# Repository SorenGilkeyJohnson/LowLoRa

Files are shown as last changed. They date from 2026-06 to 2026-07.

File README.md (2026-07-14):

# Low Power LoRa Weather Station

A solar powered, batteryless LoRa (expandable) sensor node powered from a supercapacitor charged by a small solar cell using an energy harvester. This was built around the Semtech SX1262 LoRa transceiver (US band; 915 MHz) and the low power MSPM0L110x MCU (TI; M0+), this board is a monitoring platform for anything you might want! The board is made around the solar cell and is roughly 23x24mm. 

<p align="center">
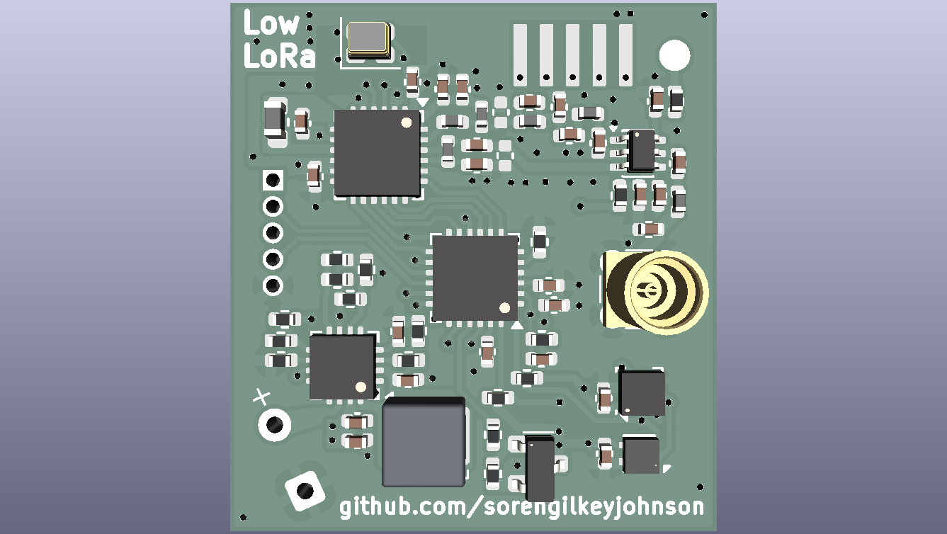
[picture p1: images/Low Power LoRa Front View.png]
Front View
  
</p>

## Overview

When researching this concept, I had found a few previous examples of this being done (e.g. [nootropicdesign](hackster.io/nootropicdesign/solar-powered-lora-weather-station-36b6ea)). I had not found an example, however, of a board that was fully self contained. When I was researching the component selection I really wanted it to be fully on board, which drove my decision to use a supercapacitor over a traditional Li-ION cell (almost none are SMD) and made me want to use a chip or PCB antenna. I found a supercapacitor that should work (this is my first time working with them), but I did not have enough room for an onboard antenna. Because of this I decided to add an external antenna through a connector. Another reason for this is the solar cell can block the RF waves from propagating properly. My project is still fairly unique from any existing solution, because I have found that it is rare to use a SMD solar cell. This is one of the biggest ones available on the market, as most are designed for handheld calculators. 
    Figuring out the power budget was very difficult for this project, and that was probably the thing I spent the most time on. Thankfully, the SX1262 datasheet had detailed power budget options, and I was able to base it off of that (almost all of my battery consumption should be from that). This project taught me a lot about the importance of component selection! (I probably spent 2 times longer on this than any other project I had done vs the routing). 
    When I get the board, I hope I can get it so that it is watertight. I have already done some research into gaskets for the humidity sensor (as this needs access to the outside world to get a good reading), but this seems pretty hard to do. There is a version of the sensor that has this built in, but it is far more expensive and is hard to get from most suppliers. I plan to use silicone around the PCB to protect the border of the solar cell from accidental damage, and put a piece of fiberglass over it. I made sure to keep all the parts that would petrude together, so I should have a slightly easier time designing the case. I hope I can get this board and test it out soon!

## Key Features

* **Ultra Low Power** This PCB should run at ultra low power, and may be able to run continuously in good sunlight (although it is designed for far less).
* **Small Board Size** The board for this is quite compact, and is mainly constrained by the size of the solar cell.
* **LoRa Transmit** This should be able to transfer over very long distances, and should be able to also extend range of other forming a "mesh"
* **Future expansion** Plentiful GPIO pins are broken out, so if one wanted to add more sensors, it would be as easy as soldering additional connectors to the PCB test pads.

## How It Works

1. The solar cell charges a supercapacitor through the BQ25504 energy harvesting IC, which is designed to extract power efficiently over a long period of time from very low amperage power sources. The datasheet mentioned being able to charge off of a piezoelectric element which would be way under the amount of current generated by a solar cell. Hopefully, this will overcome the natural discharge of the supercap.
2. A PMOS, switched by the MCU, gates power (VSYS) to the SX1262 and sensors, keeping the idle current as low as possible between transmissions because far less of the passive components are powered, and everything remains fully off.
3. The MSPM0L110x wakes periodically (very low sleep current ~<1uA; nothing compared to capacitor discharge), turns on the MOSFET to wake the sensors, reads the temperature/humidity and pressure sensors over I2C, and transmits the data over LoRa using the SX1262. Monitors the BAT_GOOD pin and turns everything off when it needs to!
4. The system was sized so that the supercapacitor can supply more than enough for the estimated ~15–30 mJ needed for a transmit burst. This part selection could be more conservative, but it was outside the range of ceramic capacitors, and there were not a lot of good low profile supercapacitor options.

## Hardware

| Main Components | Part | Notes |
| --- | --- | --- |
| LoRa Transceiver | SX1262 | Main IC, tuned for 915 MHz (US LoRa band) |
| Antenna | MMCX connector | External antenna due to PCB space constraints and having a metal backing (solar cell) |
| MCU | MSPM0L110x | I2C + SPI, wide voltage range, low cost, high availability from LCSC |
| Energy Harvester | BQ25504 | Manages charging from the solar cell and is very efficient. Gold standard for applications like this. |
| Solar Cell | KXOB121K04F-TR | very nice solar cell available on Digikey |
| Energy Storage | CXP-3R0335R-TW Supercapacitor | Low ESR; high capacitance; relatively space efficient |
| Load Switch | PMOS | Controlled by MCU to gate VSYS in order to save power for the rest of the system |
| Humidity/Temp Sensor | SHT4x | I2C |
| Pressure Sensor | LPS22HB | I2C |
| Antenna Switch | PE4259 | RF switch for the SX1262 (exact same component from reference design) |
| PCB Size | 23 mm x 25 mm | Large Solar Cell at a relatively high voltage compared to others on the market |

### 3D Renders

### PCB Layers
<p align="center">
  Front View
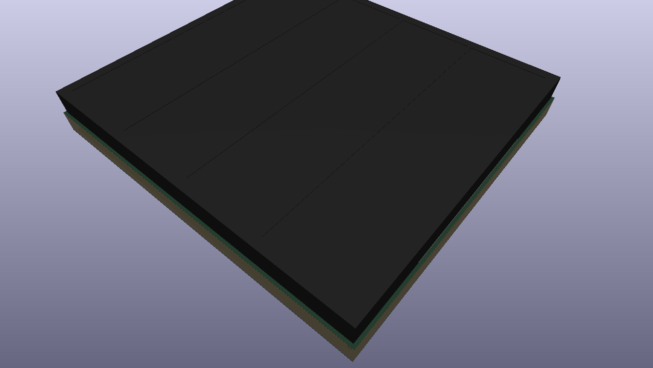
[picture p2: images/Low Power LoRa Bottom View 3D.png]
Bottom View
  
</p>

### PCB Layers

<p align="center">
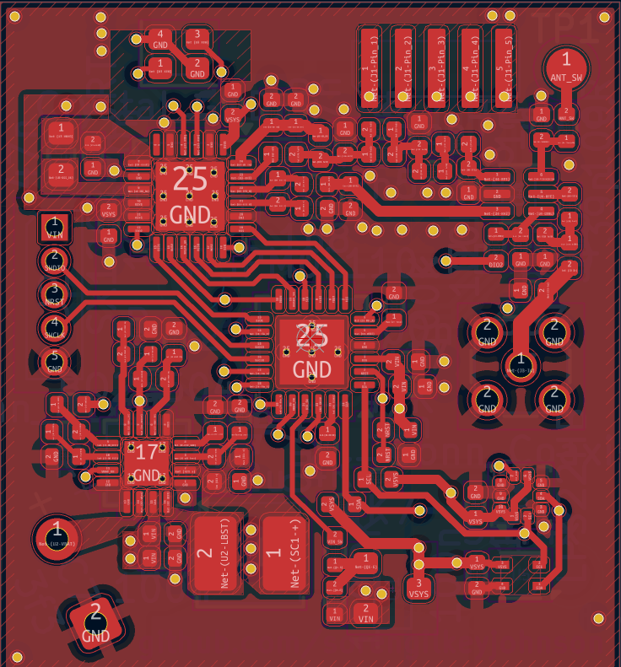
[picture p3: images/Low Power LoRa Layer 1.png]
Layer 1
  
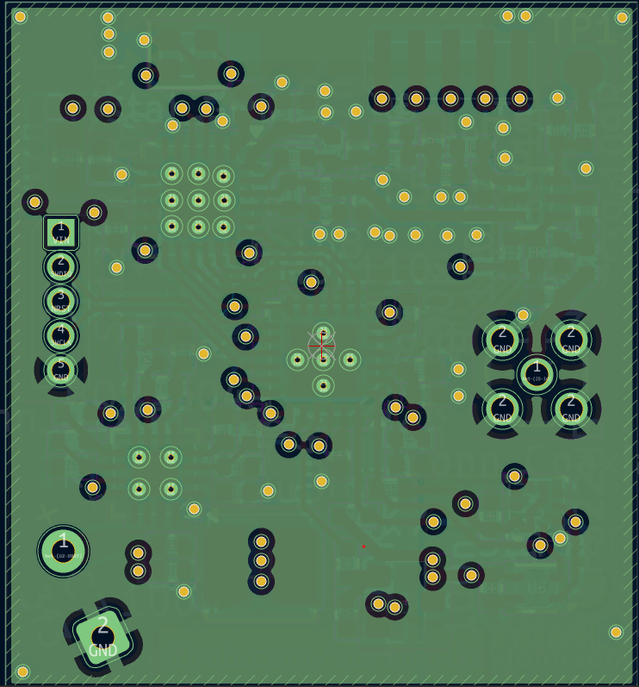
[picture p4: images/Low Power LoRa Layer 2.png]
Layer 2
  
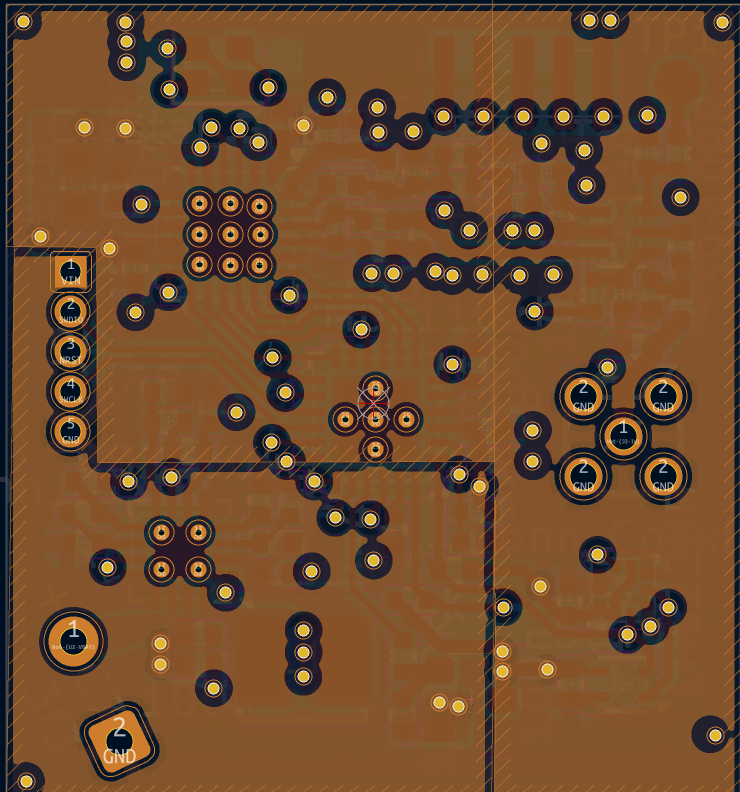
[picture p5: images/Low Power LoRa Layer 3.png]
Layer 3
  
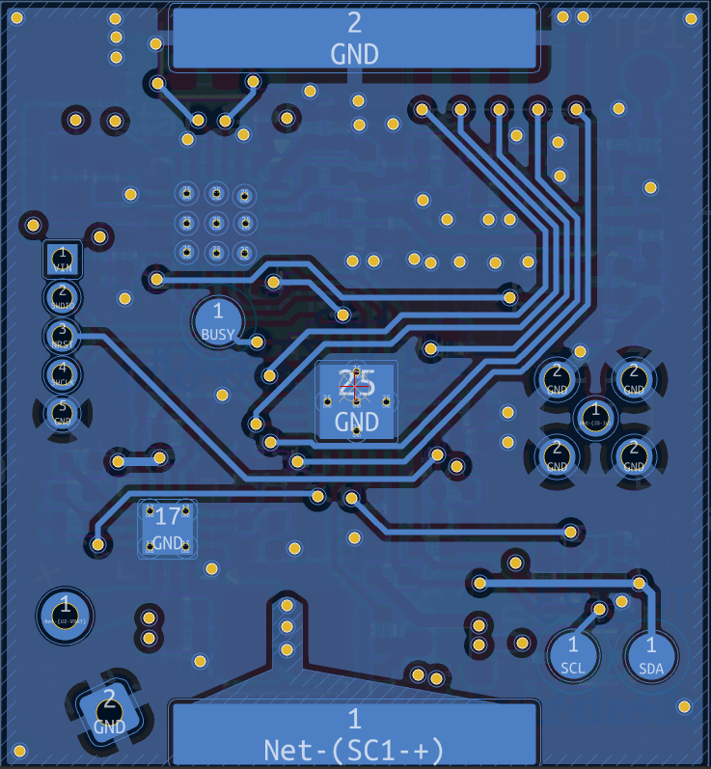
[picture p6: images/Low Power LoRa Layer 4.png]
Layer 4
  
</p>

Schematic: [`Low Power LoRa Schematic.pdf`](https://www.google.com/search?q=images/Low%2520Power%2520LoRa%2520Schematic.pdf)

## Repository Structure

```
.
├── KiCAD/
│  ├── Low Power LoRa.kicad_pcb     # PCB layout
│  ├── Low Power LoRa.kicad_prl     # Project local settings
│  ├── Low Power LoRa.kicad_pro     # Project file
│  └── Low Power LoRa.kicad_sch     # Schematic
├── fabrication/
│  ├── bom.csv                      # Bill of materials
│  ├── gerbers.zip                  # Gerber files for PCB fabrication
│  └── pick_and_place.csv           # Pick-and-place file for assembly
├── images/
│  ├── Low Power LoRa Bottom View 3D.png
│  ├── Low Power LoRa Front View.png
│  ├── Low Power LoRa Layer 1.png
│  ├── Low Power LoRa Layer 2.png
│  ├── Low Power LoRa Layer 3.png
│  ├── Low Power LoRa Layer 4.png
│  └── Low Power LoRa Schematic.pdf
├── LICENSE
└── README.md

```

## Ordering the Board

Fabrication files can be found here: [`fabrication/`](https://www.google.com/search?q=fabrication/) folder:
The BOM was generated using LCSC, so ignore the minimum part quantities (these get messed up due to MOQ). You should be able to use the KiCAD files to generate your own.

## Programming

The MSPM0L110x is programmed with the SWD header. I do not have the board yet, so I will update this section more later when I have more information about real-world testing.

## Acknowledgments

* SX1262 RF matching network and BQ25504 based on respective companies reference design
* Review from r/PrintedCircuitBoard! (Thank you!)

## License

See [`LICENSE`](https://www.google.com/search?q=LICENSE) for details.

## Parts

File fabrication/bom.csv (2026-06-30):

Reference | Qty | Value | DNP | Exclude from BOM | Exclude from Board | Footprint | Datasheet
C1,C5 | 2 | 10n |  |  |  | Capacitor_SMD:C_0402_1005Metric
C2,C6,C8 | 3 | 4u7 |  |  |  | Capacitor_SMD:C_0402_1005Metric
C3,C10,C11,C22,C29 | 5 | 100n |  |  |  | Capacitor_SMD:C_0402_1005Metric
C4 | 1 | 0u47 |  |  |  | Capacitor_SMD:C_0402_1005Metric
C7 | 1 | 3F3 |  |  |  | Capacitor_THT:CP_Radial_D8.0mm_P3.50mm
C9 | 1 | 1u |  |  |  | Capacitor_SMD:C_0402_1005Metric
C12 | 1 | 470n |  |  |  | Capacitor_SMD:C_0402_1005Metric
C13 | 1 | 47n |  |  |  | Capacitor_SMD:C_0402_1005Metric
C14,C23 | 2 | 1p8 |  |  |  | Capacitor_SMD:C_0402_1005Metric
C15 | 1 | 47p |  |  |  | Capacitor_SMD:C_0402_1005Metric
C16 | 1 | 2p4 |  |  |  | Capacitor_SMD:C_0402_1005Metric
C19 | 1 | 3p |  |  |  | Capacitor_SMD:C_0402_1005Metric
C20 | 1 | 5p6 |  |  |  | Capacitor_SMD:C_0402_1005Metric
C21,C26 | 2 | 39p |  |  |  | Capacitor_SMD:C_0402_1005Metric
C24,C25 | 2 | 1n |  |  |  | Capacitor_SMD:C_0402_1005Metric
C27,C28 | 2 | 3p3 |  |  |  | Capacitor_SMD:C_0402_1005Metric
J1 | 1 | Conn_01x05 |  |  |  | Connector_PinHeader_1.27mm:PinHeader_1x05_P1.27mm_Vertical_SMD_Pin1Left
J2 | 1 | Conn_01x05 |  |  |  | Connector_PinHeader_1.27mm:PinHeader_1x05_P1.27mm_Vertical
J3 | 1 | Conn_Coaxial |  |  |  | Connector_Coaxial:MMCX_Molex_73415-1471_Vertical
L1 | 1 | 22u |  |  |  | Inductor_SMD:L_Wuerth_LQFS-3818
L2 | 1 | 47n |  |  |  | Inductor_SMD:L_0603_1608Metric
L3 | 1 | 0R |  |  |  | Inductor_SMD:L_0402_1005Metric
L4 | 1 | 15n |  |  |  | Inductor_SMD:L_0402_1005Metric
L5 | 1 | 47n |  |  |  | Inductor_SMD:L_0402_1005Metric
L6 | 1 | 2n5 |  |  |  | Inductor_SMD:L_0402_1005Metric
L7 | 1 | 4n7 |  |  |  | Inductor_SMD:L_0402_1005Metric
L8 | 1 | 9n1 |  |  |  | Inductor_SMD:L_0402_1005Metric
Q1 | 1 | Si2301CDS |  |  |  | PCM_Package_TO_SOT_SMD_AKL:SOT-23 | https://www.tme.eu/Document/519498819e90b407235adccdceba4014/SI2301CDS-T1-GE3.pdf
R1 | 1 | 47K |  |  |  | Resistor_SMD:R_0402_1005Metric
R2,R3,R4,R5,R6,R7,R8,R9,R10 | 9 | R |  |  |  | Resistor_SMD:R_0402_1005Metric
R11,R12 | 2 | 100K |  |  |  | Resistor_SMD:R_0402_1005Metric
R13 | 1 | 10K |  |  |  | Resistor_SMD:R_0402_1005Metric
R14,R15 | 2 | 4K7 |  |  |  | Resistor_SMD:R_0402_1005Metric
R16,R17 | 2 | 100R |  |  |  | Resistor_SMD:R_0402_1005Metric
SC1 | 1 | KXOB121K04F-TR |  |  |  | Custom_Footprint_Purchase:KXOB121K04F-TR
TP1,TP2,TP3,TP4 | 4 | TestPoint |  |  |  | TestPoint:TestPoint_Pad_D1.5mm
U1 | 1 | MSPM0L110x |  |  |  | Package_DFN_QFN:VQFN-24-1EP_4x4mm_P0.5mm_EP2.45x2.45mm_ThermalVias | https://www.ti.com/lit/gpn/mspm0l1105
U2 | 1 | BQ25504 |  |  |  | Package_DFN_QFN:VQFN-16-1EP_3x3mm_P0.5mm_EP1.68x1.68mm_ThermalVias | http://www.ti.com/lit/ds/symlink/bq25504.pdf
U3 | 1 | SX1262IMLTRT |  |  |  | Package_DFN_QFN:QFN-24-1EP_4x4mm_P0.5mm_EP2.6x2.6mm | https://semtech.file.force.com/sfc/dist/version/download/?oid=00DE0000000JelG&ids=0682R00000IjPWSQA3
U4 | 1 | PE4259 |  |  |  | Package_TO_SOT_SMD:SOT-363_SC-70-6 | 4259-63
U5 | 1 | SHT4x |  |  |  | Sensor_Humidity:Sensirion_DFN-4_1.5x1.5mm_P0.8mm_SHT4x_NoCentralPad | https://sensirion.com/media/documents/33FD6951/624C4357/Datasheet_SHT4x.pdf
U7 | 1 | LPS22HH |  |  |  | Package_LGA:ST_HLGA-10_2x2mm_P0.5mm_LayoutBorder3x2y | https://www.st.com/resource/en/datasheet/lps22hh.pdf
Y1 | 1 | Crystal_GND24 |  |  |  | Crystal:Crystal_SMD_2520-4Pin_2.5x2.0mm

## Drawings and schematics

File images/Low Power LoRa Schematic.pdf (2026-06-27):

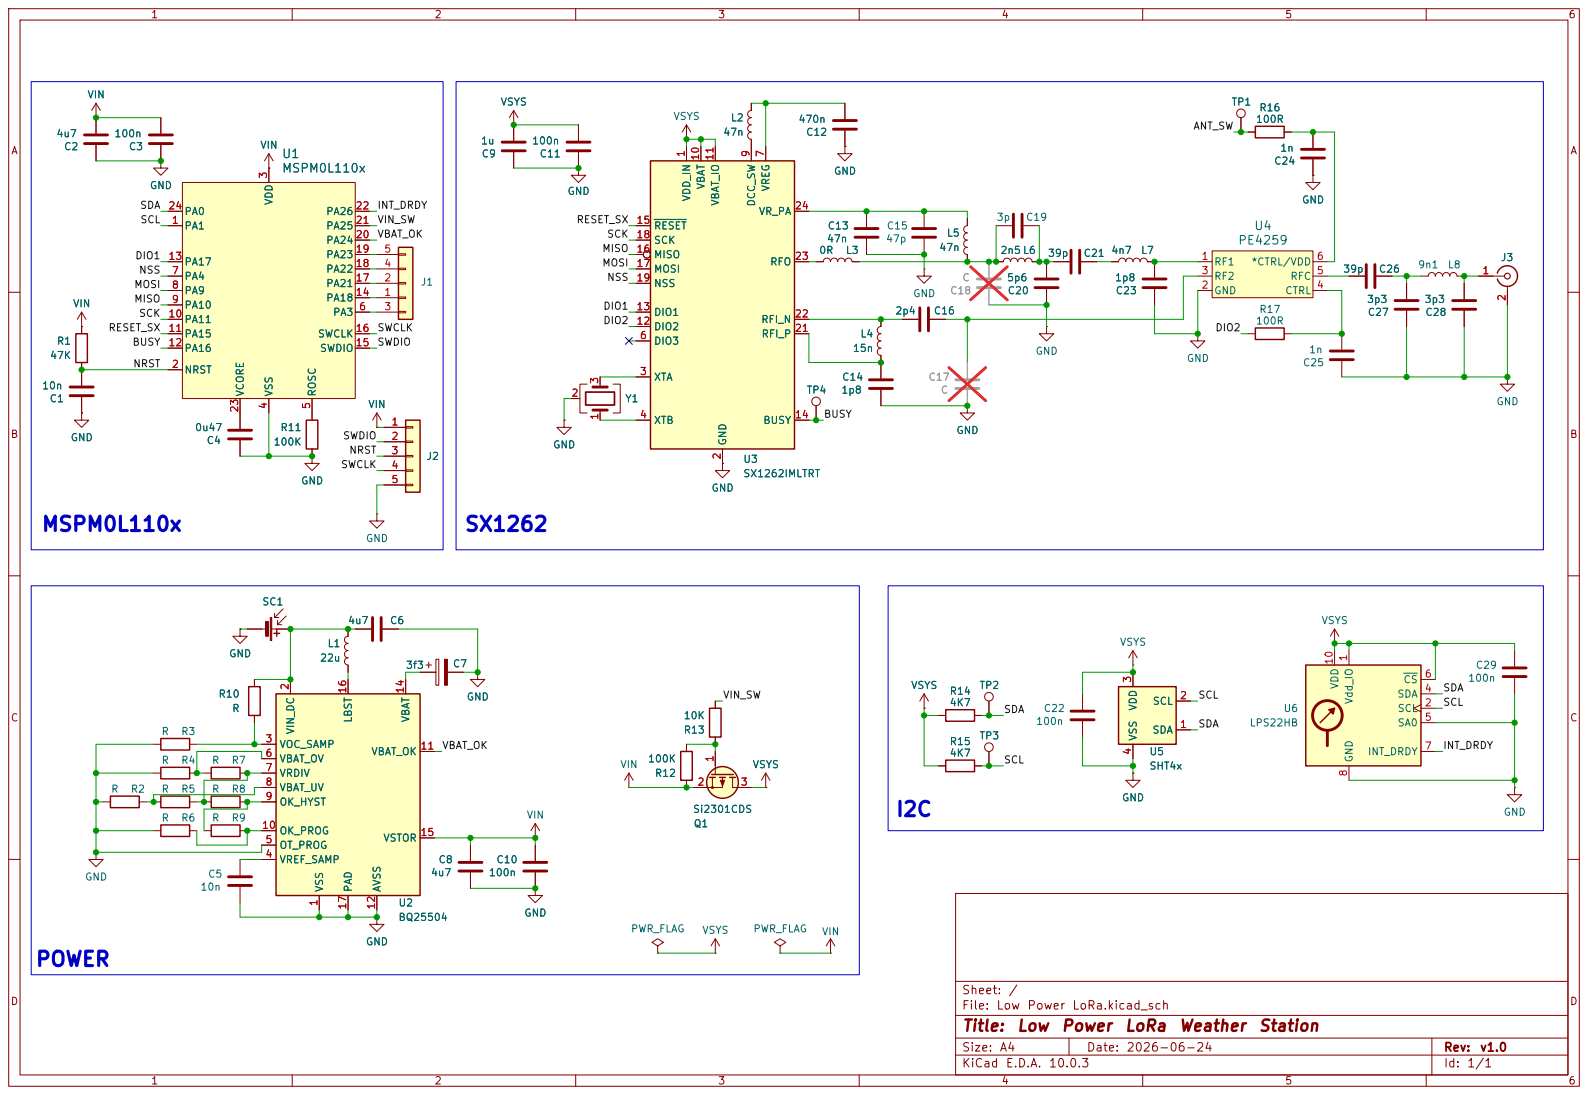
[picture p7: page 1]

9 VBAT 10 VBAT_IO 11 DIO2 12 DIO1 13 BUSY 14 RESET 15 MISO 16 MOSI 17

BUSY BUSY SDA SCL RESET_SX DIO1

SCL NSS MISO MOSI SCK

Sheet: /
File: Low Power LoRa.kicad_sch
Title: Low Power LoRa Weather Station

Size: A4 | Rev: v1.0
KiCad E.D.A. 10.0.3 | Id: 1/1

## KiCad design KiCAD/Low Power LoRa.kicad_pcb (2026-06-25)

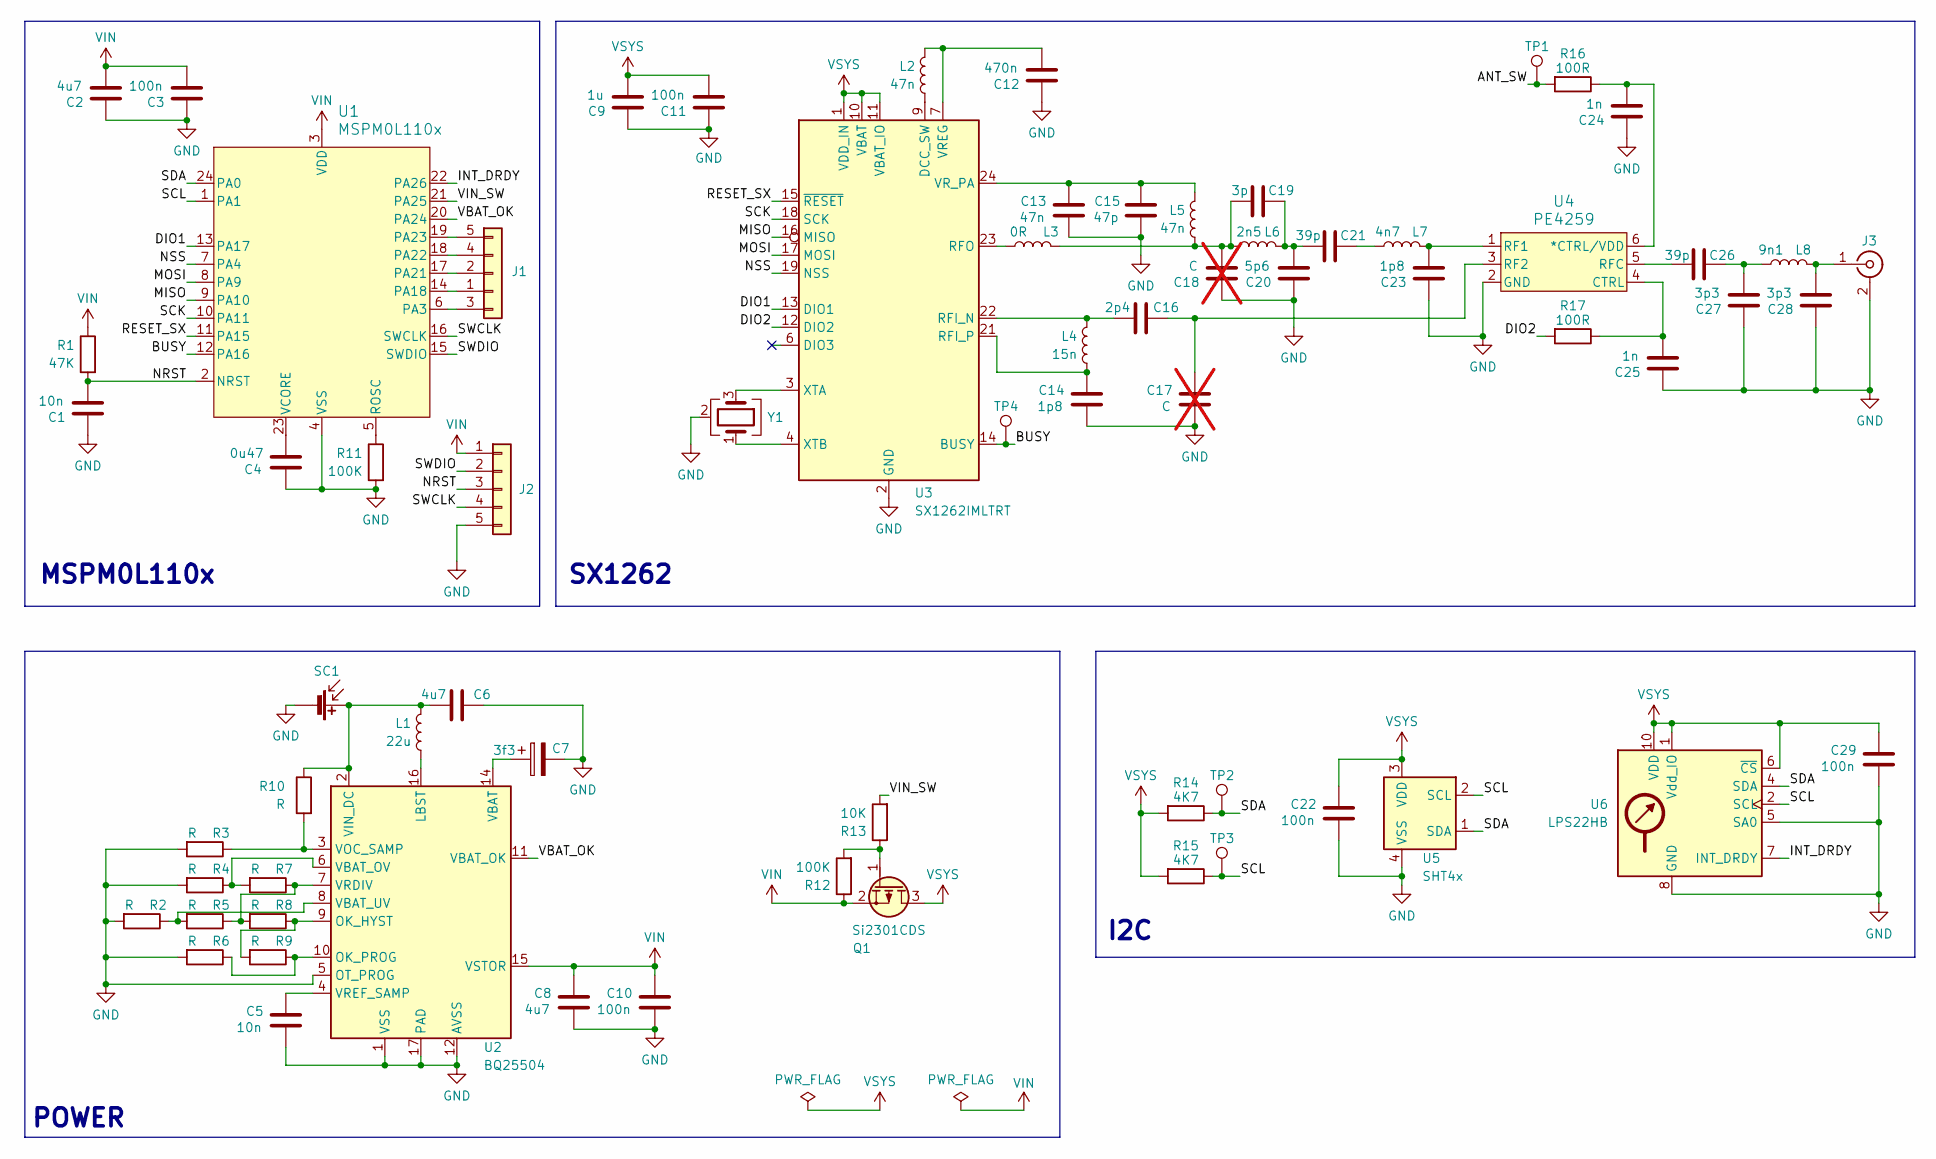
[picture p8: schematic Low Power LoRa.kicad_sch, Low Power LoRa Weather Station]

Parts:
C1, C5: 10n; C_0402_1005Metric
C2, C6, C8: 4u7; C_0402_1005Metric
C3, C10, C11, C22, C29: 100n; C_0402_1005Metric
C4: 0u47; C_0402_1005Metric
C7: 3f3; CP_Radial_D8.0mm_P3.50mm
C9: 1u; C_0402_1005Metric
C12: 470n; C_0402_1005Metric
C13: 47n; C_0402_1005Metric
C14, C23: 1p8; C_0402_1005Metric
C15: 47p; C_0402_1005Metric
C16: 2p4; C_0402_1005Metric
C17, C18: C; C_0402_1005Metric; not fitted
C19: 3p; C_0402_1005Metric
C20: 5p6; C_0402_1005Metric
C21, C26: 39p; C_0402_1005Metric
C24, C25: 1n; C_0402_1005Metric
C27, C28: 3p3; C_0402_1005Metric
J1: Conn_01x05; PinHeader_1x05_P1.27mm_Vertical_SMD_Pin1Left
J2: Conn_01x05; PinHeader_1x05_P1.27mm_Vertical
J3: Conn_Coaxial; MMCX_Molex_73415-1471_Vertical
L1: 22u; L_Wuerth_LQFS-3818
L2: 47n; L_0603_1608Metric
L3: 0R; L_0402_1005Metric
L4: 15n; L_0402_1005Metric
L5: 47n; L_0402_1005Metric
L6: 2n5; L_0402_1005Metric
L7: 4n7; L_0402_1005Metric
L8: 9n1; L_0402_1005Metric
Q1: Si2301CDS; SOT-23
R1: 47K; R_0402_1005Metric
R2, R3, R4, R5, R6, R7, R8, R9, R10: R; R_0402_1005Metric
R11, R12: 100K; R_0402_1005Metric
R13: 10K; R_0402_1005Metric
R14, R15: 4K7; R_0402_1005Metric
R16, R17: 100R; R_0402_1005Metric
SC1: KXOB121K04F-TR
TP1, TP2, TP3, TP4: TestPoint; TestPoint_Pad_D1.5mm
U1: MSPM0L110x; VQFN-24-1EP_4x4mm_P0.5mm_EP2.45x2.45mm_ThermalVias
U2: BQ25504; VQFN-16-1EP_3x3mm_P0.5mm_EP1.68x1.68mm_ThermalVias
U3: SX1262IMLTRT; QFN-24-1EP_4x4mm_P0.5mm_EP2.6x2.6mm
U4: PE4259; SOT-363_SC-70-6
U5: SHT4x; Sensirion_DFN-4_1.5x1.5mm_P0.8mm_SHT4x_NoCentralPad
U6: LPS22HB; ST_HLGA-10_2x2mm_P0.5mm_LayoutBorder3x2y
Y1: Crystal_GND24; Crystal_SMD_2016-4Pin_2.0x1.6mm

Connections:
/ANT_SW: R16.2, TP1.1 (1_1)
/BUSY: TP4.1 (1_1), U1.12 (PA16), U3.14 (BUSY)
/DIO1: U1.13 (PA17), U3.13 (DIO1)
/DIO2: R17.2, U3.12 (DIO2)
/INT_DRDY: U1.22 (PA26), U6.7 (INT_DRDY)
/MISO: U1.9 (PA10), U3.16 (MISO)
/MOSI: U1.8 (PA9), U3.17 (MOSI)
/NRST: C1.2, J2.3, R1.2, U1.2 (NRST)
/NSS: U1.7 (PA4), U3.19 (NSS)
/RESET_SX: U1.11 (PA15), U3.15 (~RESET)
/SCK: U1.10 (PA11), U3.18 (SCK)
/SCL: R15.1, TP3.1 (1_1), U1.1 (PA1), U5.2 (SCL), U6.2 (SCL)
/SDA: R14.1, TP2.1 (1_1), U1.24 (PA0), U5.1 (SDA), U6.4 (SDA)
/SWCLK: J2.4, U1.16 (SWCLK)
/SWDIO: J2.2, U1.15 (SWDIO)
/VBAT_OK: U1.20 (PA24), U2.11 (VBAT_OK)
/VIN_SW: R13.2, U1.21 (PA25)
GND: C1.1, C2.1, C3.1, C4.2, C5.2, C6.1, C7.2, C8.2, C9.1, C10.2, C11.1, C12.1, C13.2, C14.2, C15.2, C17.2, C18.1, C20.1, C22.2, C23.1, C24.1, C25.1, C27.1, C28.1, C29.2, J2.5, J3.2 (Ext), R2.2, R3.2, R4.2, R6.2, R11.2, SC1.2 (-), U1.4 (VSS), U1.25 (VSS), U2.1 (VSS), U2.5 (OT_PROG), U2.12 (AVSS), U2.13 (VSS), U2.17 (PAD), U3.2 (GND), U3.5 (GND), U3.8 (GND), U3.20 (GND), U3.25 (GND), U4.2 (GND), U5.4 (VSS), U6.3 (GND), U6.5 (SA0), U6.8 (GND), U6.9 (GND), Y1.2 (G), Y1.4 (G)
unnamed: C18.2, C19.2, L3.2, L5.2, L6.1
unnamed: C19.1, C20.2, C21.2, L6.2
unnamed: C21.1, L7.1
unnamed: C26.1, C27.2, L8.1
unnamed: J1.1, U1.14 (PA18)
unnamed: J1.2, U1.17 (PA21)
unnamed: J1.3, U1.6 (PA3)
unnamed: J1.4, U1.18 (PA22)
unnamed: J1.5, U1.19 (PA23)
unnamed: C28.2, J3.1 (In), L8.2
unnamed: Q1.1 (G), R12.2, R13.1
unnamed: C6.2, L1.1, R10.1, SC1.1 (+), U2.2 (VIN_DC)
unnamed: R11.1, U1.5 (ROSC)
unnamed: C4.1, U1.23 (VCORE)
unnamed: L1.2, U2.16 (LBST)
unnamed: R8.1, R9.2, U2.9 (OK_HYST)
unnamed: R6.1, R9.1, U2.10 (OK_PROG)
unnamed: C7.1, U2.14 (VBAT)
unnamed: R4.1, R7.2, U2.6 (VBAT_OV)
unnamed: R2.1, R5.2, U2.8 (VBAT_UV)
unnamed: R3.1, R10.2, U2.3 (VOC_SAMP)
unnamed: R5.1, R7.1, R8.2, U2.7 (VRDIV)
unnamed: C5.1, U2.4 (VREF_SAMP)
unnamed: L2.2, U3.9 (DCC_SW)
unnamed: C16.2, L4.1, U3.22 (RFI_N)
unnamed: C14.1, L4.2, U3.21 (RFI_P)
unnamed: L3.1, U3.23 (RFO)
unnamed: C12.2, L2.1, U3.7 (VREG)
unnamed: C13.1, C15.1, L5.1, U3.24 (VR_PA)
unnamed: U3.3 (XTA), Y1.3
unnamed: U3.4 (XTB), Y1.1
unnamed: C24.2, R16.1, U4.6 (*CTRL/VDD)
unnamed: C25.2, R17.1, U4.4 (CTRL)
unnamed: C23.2, L7.2, U4.1 (RF1)
unnamed: C16.1, C17.1, U4.3 (RF2)
unnamed: C26.2, U4.5 (RFC)
VIN: C2.2, C3.2, C8.1, C10.1, J2.1, Q1.2 (S), R1.1, R12.1, U1.3 (VDD), U2.15 (VSTOR)
VSYS: C9.2, C11.2, C22.1, C29.1, Q1.3 (D), R14.2, R15.2, U3.1 (VDD_IN), U3.10 (VBAT), U3.11 (VBAT_IO), U5.3 (VDD), U6.1 (Vdd_IO), U6.6 (~CS), U6.10 (VDD)

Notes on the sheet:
I2C
POWER
SX1262
MSPM0L110x

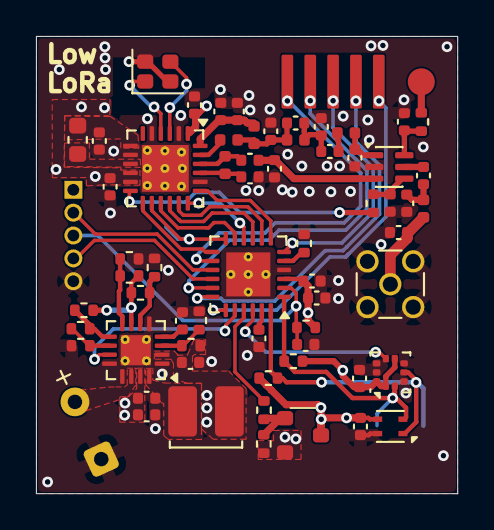
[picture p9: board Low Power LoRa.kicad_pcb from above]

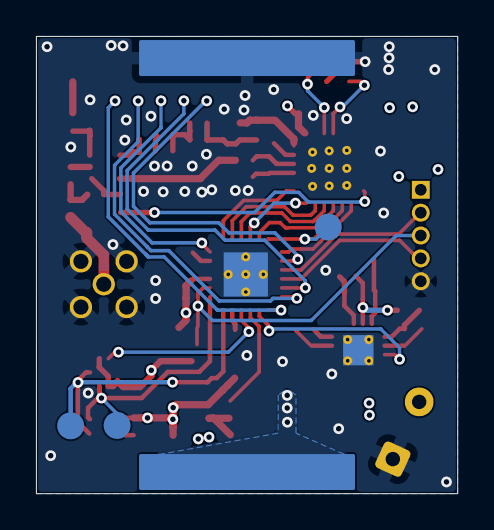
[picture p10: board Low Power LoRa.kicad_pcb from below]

Board: 4 copper layers, 23.4 x 25.4 mm, 70 parts (4 on the bottom side), 56 nets.

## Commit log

2026-06-25 Rename Low Power LoRa.kicad_pcb to KiCAD/Low Power LoRa.kicad_pcb
    [Low Power LoRa.kicad_pcb]
2026-06-25 Rename Low Power LoRa.kicad_prl to KiCAD/Low Power LoRa.kicad_prl
2026-06-25 Rename Low Power LoRa.kicad_pro to KiCAD/Low Power LoRa.kicad_pro
2026-06-25 Rename Low Power LoRa.kicad_sch to KiCAD/Low Power LoRa.kicad_sch
    [Low Power LoRa.kicad_sch]
2026-06-27 Rename Low Power LoRa Schematic.pdf to images/Low Power LoRa Schematic.pdf
2026-06-27 Rename Low Power LoRa Layer 1.png to images/Low Power LoRa Layer 1.png
2026-06-27 Rename Low Power LoRa Layer 2.png to images/Low Power LoRa Layer 2.png
2026-06-27 Rename Low Power LoRa Layer 3.png to images/Low Power LoRa Layer 3.png
2026-06-27 Rename Low Power LoRa Layer 4.png to images/Low Power LoRa Layer 4.png
2026-06-27 Rename Low Power LoRa Bottom View 3D.png to images/Low Power LoRa Bottom View 3D.png
2026-06-27 Rename Low Power LoRa Front View.png to images/Low Power LoRa Front View.png
2026-06-30 Rename Low Power LoRa_23.4x25.4mm_for_Default.zip to fabrication/gerbers.zip
2026-06-30 Rename Low Power LoRa.csv to bom.csv
    [bom.csv]
2026-06-30 Rename Low Power LoRa-all-pos.csv to fabrication/pick_and_place.csv
    [pick_and_place.csv]
2026-07-11 Adjust image widths for PCB layers
    Updated image widths for PCB layers in README.
2026-07-14 Add PCB layer images to README
    Added images of PCB layers to the README.
